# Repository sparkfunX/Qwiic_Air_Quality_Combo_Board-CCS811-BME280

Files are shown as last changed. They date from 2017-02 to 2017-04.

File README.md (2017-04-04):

Qwiic Air Quality Combo Board - CCS811 + BME280
========================================

Qwiic Air Quality Board

[*SPX-14241*](https://www.sparkfun.com/products/14241)

This combo board is the first of its kind to provide a variety of environmental data including barometric pressure, humidity, temperature, TVOCs, and CO2 levels, all over an easy to use I2C bus. The CCS811 is a very popular and very new TVOC and CO2 sensor. It has a feature that allows it to tune its internal algorithm and improve its readings if you provide the sensor with current humidity and temperature. Fortunately, the BME280 is an awesome sensor that outputs humidity, barometric pressure, and temperature. We decided to stick both on an easy to use board. We provide example code showing how to read humidity and pressure data from the BME280 and then transmit that data back to the CCS811 for improved TVOC and CO2 detection.

The [Qwiic system](http://www.sparkfun.com/qwiic) enables fast and solderless connection between popular platforms and various sensors and actuators. You can read more about the Qwiic system [here](http://www.sparkfun.com/qwiic). 

License Information
-------------------

This product is _**open source**_!

Please review the LICENSE.md file for license information.

If you have any questions or concerns on licensing, please contact techsupport@sparkfun.com.

Distributed as-is; no warranty is given.

- Your friends at SparkFun.

_<COLLABORATION CREDIT>_

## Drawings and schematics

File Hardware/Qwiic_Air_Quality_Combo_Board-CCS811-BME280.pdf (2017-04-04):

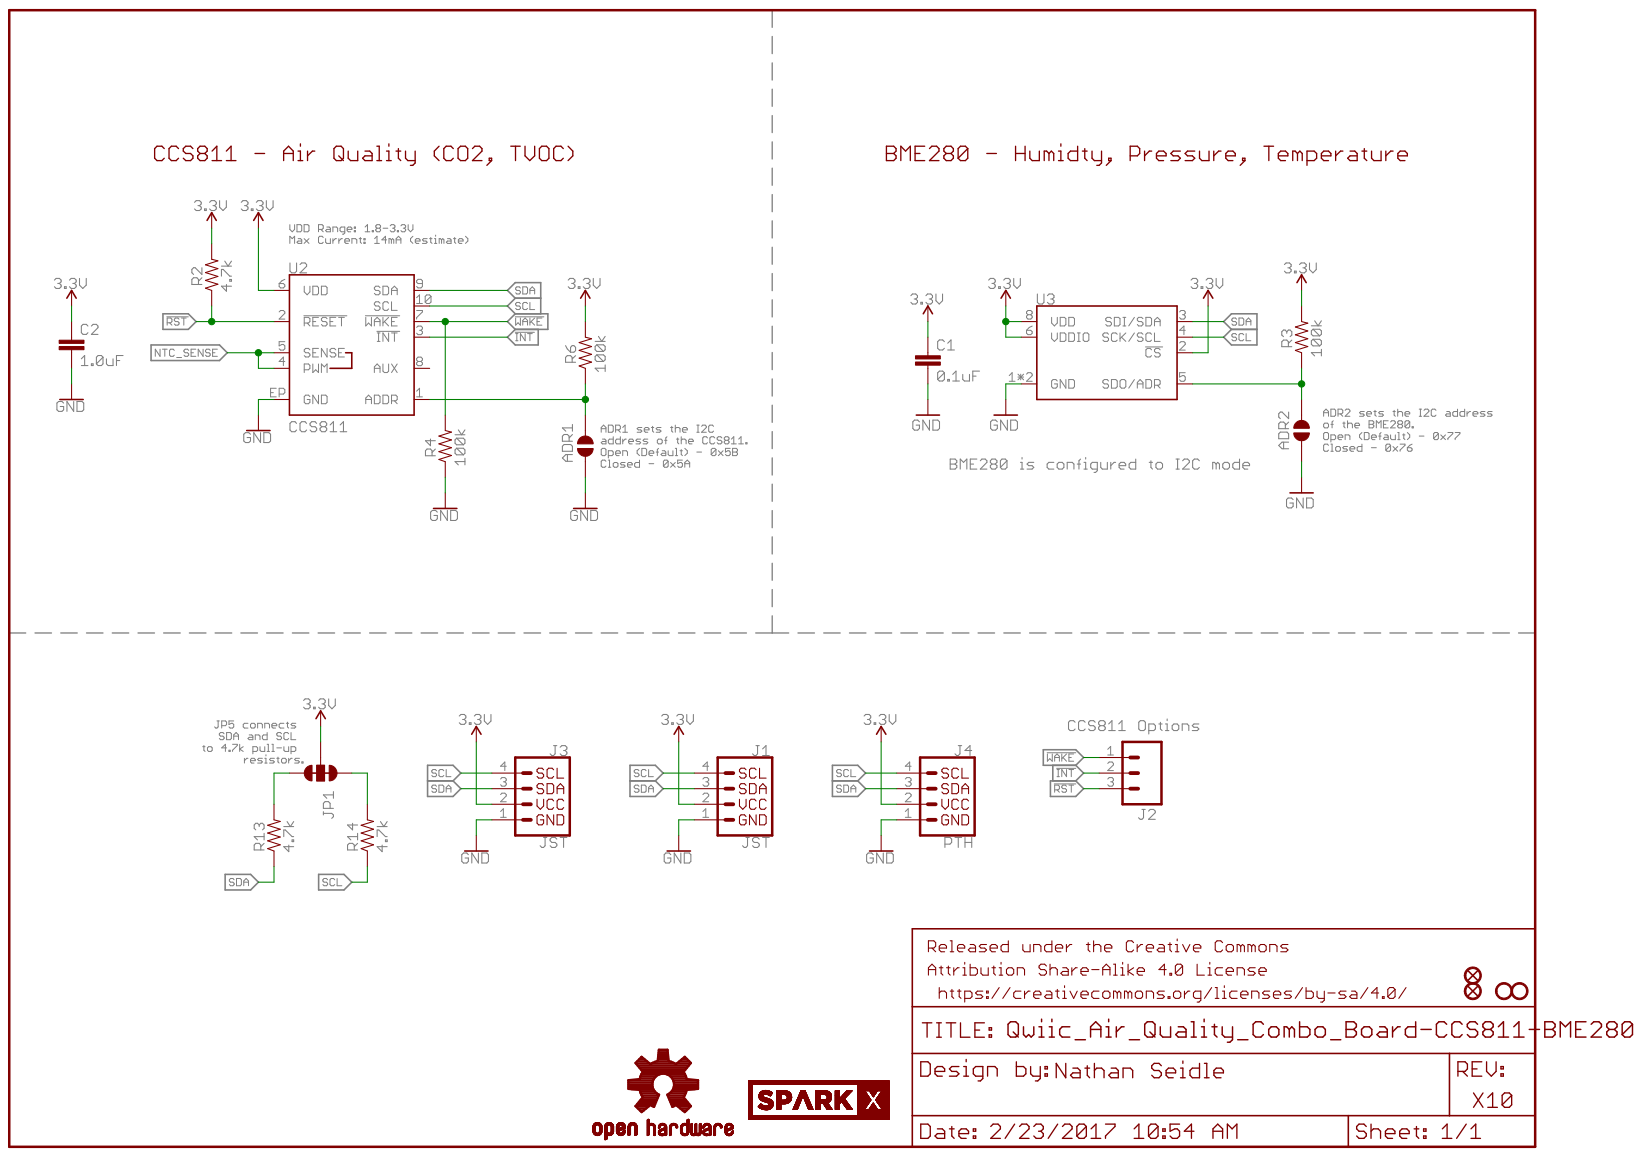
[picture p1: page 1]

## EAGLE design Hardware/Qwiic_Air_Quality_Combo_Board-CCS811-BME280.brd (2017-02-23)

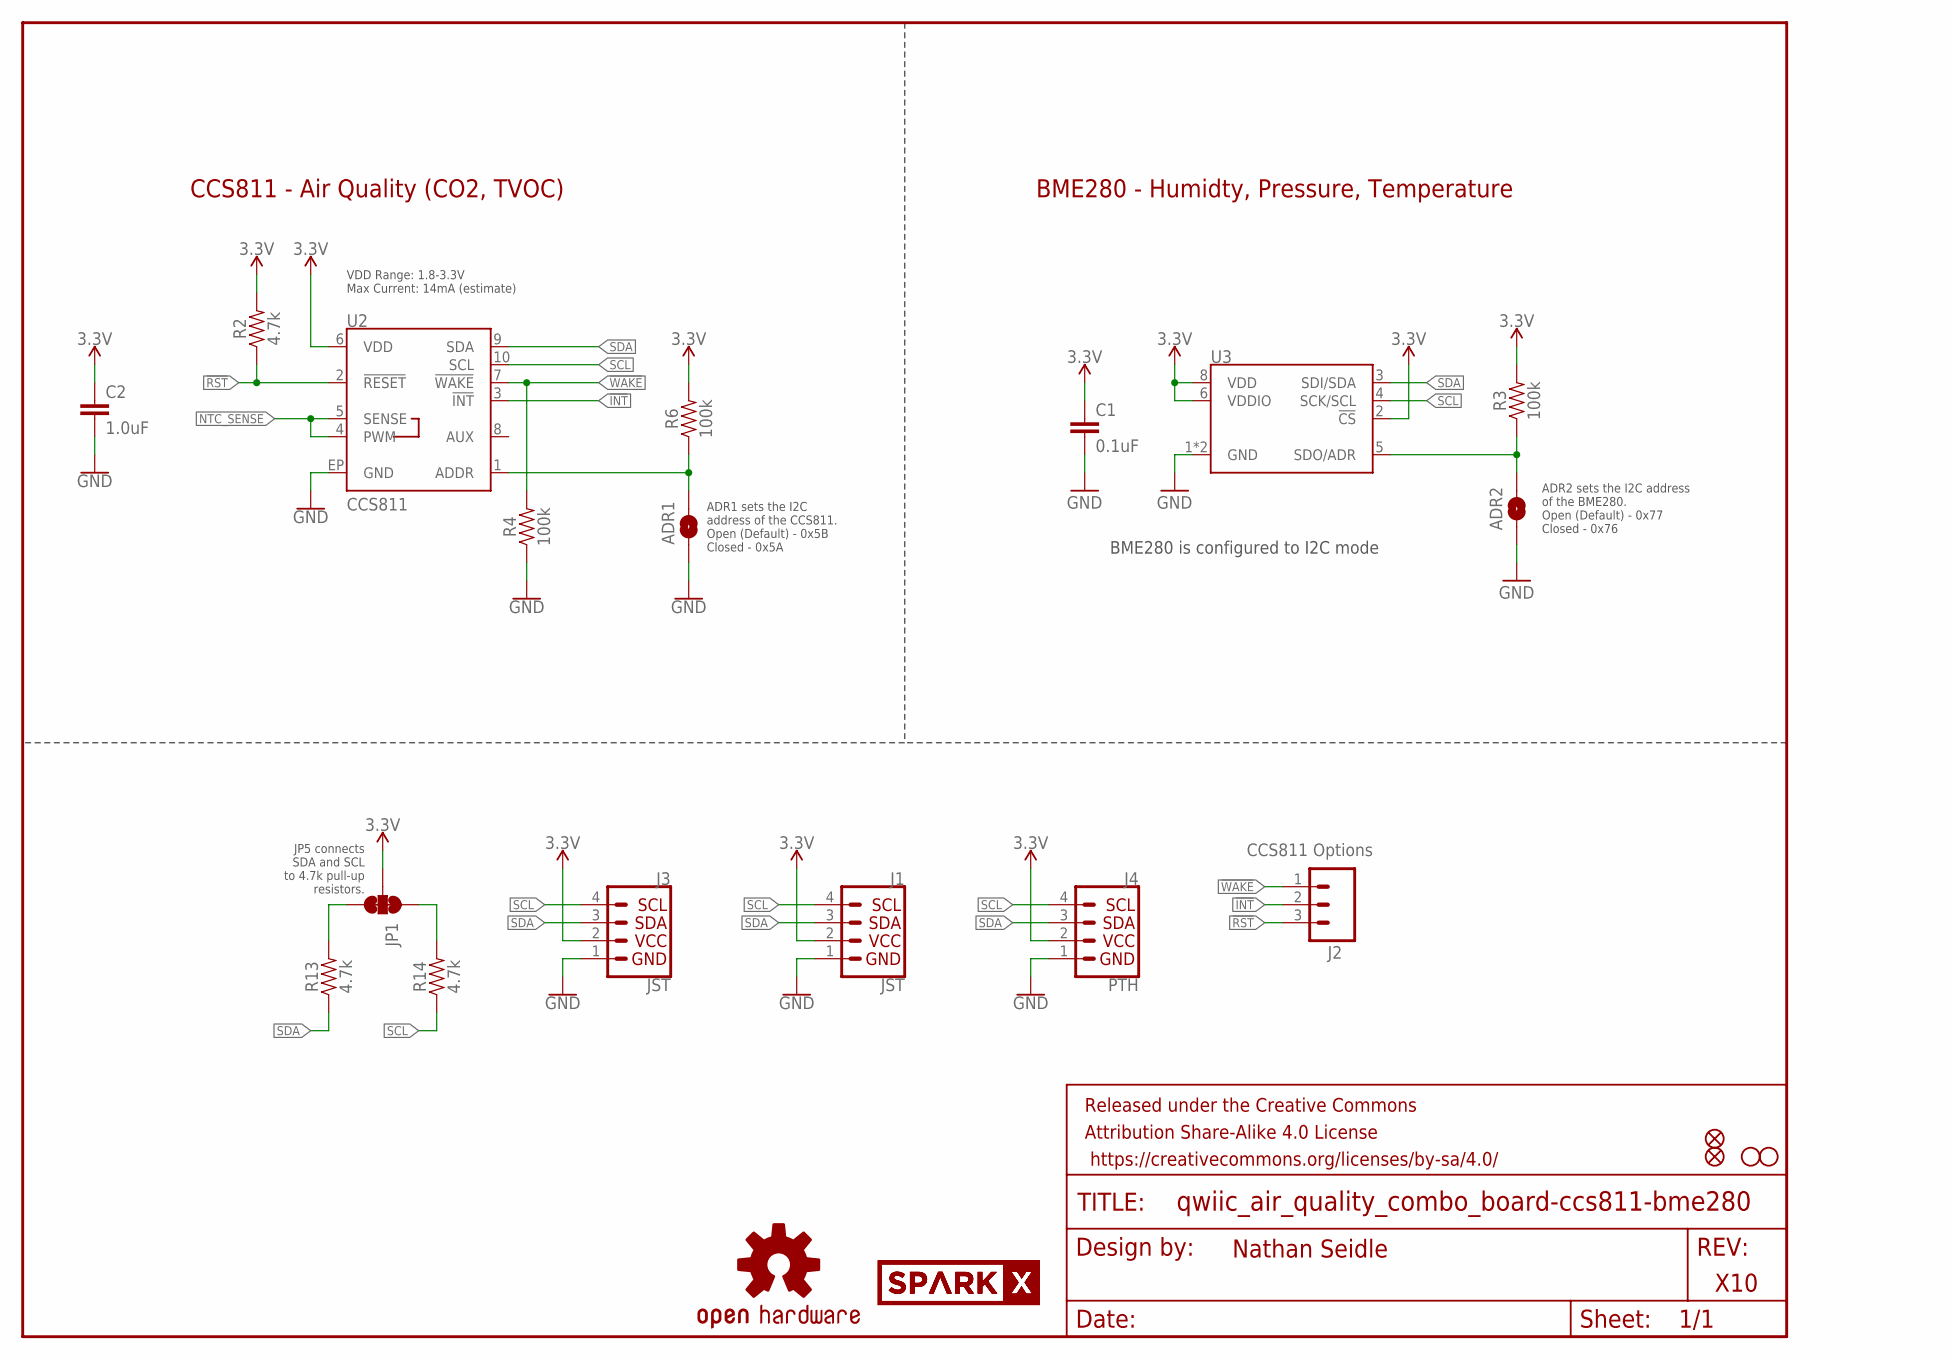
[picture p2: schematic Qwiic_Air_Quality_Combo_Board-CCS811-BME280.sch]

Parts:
ADR1, ADR2: JUMPER-SMT_2_NO_SILK; SMT-JUMPER_2_NO_SILK
C1: 0.1uF; 0603-CAP
C2: 1.0uF; 0603
FD1, FD2: FIDUCIAL1X2; FIDUCIAL-1X2
FRAME1: FRAME-LETTER; CREATIVE_COMMONS
H2, H4: STAND-OFF
J1, J3: JST; 1X04_1MM_RA
J2: CCS811 Options; 1X03_NO_SILK
J4: PTH; 1X04_NO_SILK
JP1: JUMPER-SMT_3_2-NC_TRACE_SILK; SMT-JUMPER_3_2-NC_TRACE_SILK
LOGO4: OSHW-LOGOS; OSHW-LOGO-S
R2, R13, R14: 4.7k; 0603
R3, R4, R6: 100k; 0603
U2: CCS811; LGA10
U3: BME280; BME280_LGA
U$1, U$2: SPARKX-LOGO4; SPARKX-MEDIUM

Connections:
3.3V: C1.1, C2.1, J1.2 (VCC), J3.2 (VCC), J4.2 (VCC), JP1.2, R2.2, R3.2, R6.2, U2.6 (VDD), U3.2 (!CS), U3.6 (VDDIO), U3.8 (VDD)
!INT: J2.2, U2.3 (!INT!)
!RST: J2.3, R2.1, U2.2 (!RESET!)
!WAKE: J2.1, R4.2, U2.7 (!WAKE!)
CCS811_ADDR: ADR1.2, R6.1, U2.1 (ADDR)
GND: ADR1.1, ADR2.1, C1.2, C2.2, J1.1 (GND), J3.1 (GND), J4.1 (GND), R4.1, U2.EP (GND), U3.1 (GND), U3.7 (GND)
unnamed: JP1.3, R13.2
unnamed: JP1.1, R14.2
NTC_SENSE: U2.4 (PWM), U2.5 (SENSE)
SCL: J1.4 (SCL), J3.4 (SCL), J4.4 (SCL), R14.1, U2.10 (SCL), U3.4 (SCK/SCL)
SDA: J1.3 (SDA), J3.3 (SDA), J4.3 (SDA), R13.1, U2.9 (SDA), U3.3 (SDI/SDA)
SDO/ADR: ADR2.2, R3.1, U3.5 (SDO/ADR)

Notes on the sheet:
VDD Range: 1.8-3.3V Max Current: 14mA (estimate)
CCS811 - Air Quality (CO2, TVOC)
ADR1 sets the I2C address of the CCS811. Open (Default) - 0x5B Closed - 0x5A
JP5 connects SDA and SCL to 4.7k pull-up resistors.
X10
Nathan Seidle
ADR2 sets the I2C address of the BME280. Open (Default) - 0x77 Closed - 0x76
BME280 is configured to I2C mode
BME280 - Humidty, Pressure, Temperature

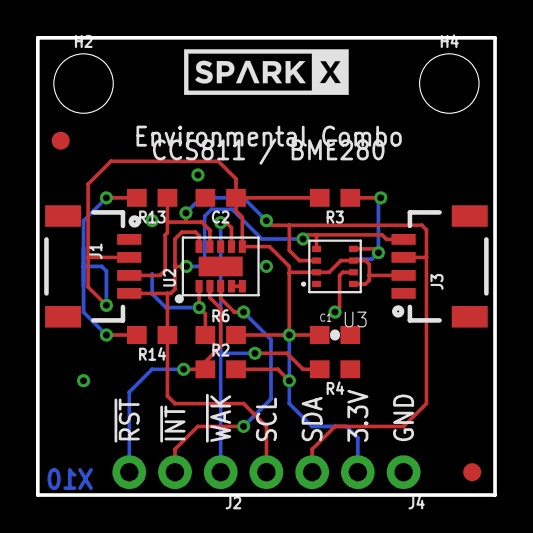
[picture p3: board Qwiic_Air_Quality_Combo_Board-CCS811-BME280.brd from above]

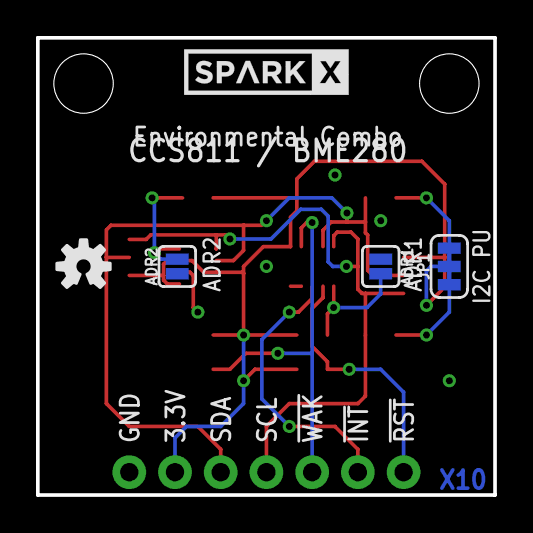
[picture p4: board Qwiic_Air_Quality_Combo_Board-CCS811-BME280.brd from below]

Board: 2 copper layers, 25.4 x 25.4 mm, 25 parts (5 on the bottom side), 12 nets.

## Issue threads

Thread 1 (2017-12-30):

problem working on esp8266

Giaitzoglou, 2017-12-30:
hi i succefully uploaded the example from your website withe combined readings but i always get an i2c error
.⸮EO⸮v`MM ⸮4C8I⸮⸮⸮H(⸮⸮⸮⸮BME280 data to CCS811 for compensation.
Problem with CCS811
I2C_ERRORProblem with BME280
can you please help me
thank in advance
chris giaitzoglou

Giaitzoglou, 2017-12-30:
i tried also the example with only the ccs811 but still having the same problem .it looks like that the i2c cant find it ?do i have to do anything to the board pullup or something i am using the qwiic to jumper cables on a breadboard with a wemos d1 mini
thanks

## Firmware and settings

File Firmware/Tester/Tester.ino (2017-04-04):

/*
  SparkFun combination CCS811 tVOC sensor combined with BME280 humidity, pressure, temp sensor
  By: Nathan Seidle
  SparkFun Electronics
  Date: April 3rd, 2017
  License: This code is public domain but you buy me a beer if you use this and we meet someday (Beerware license).

  This is a fast tester to verify both ICs are working.

  Hardware Connections:
  Attach a Qwiic Shield to your RedBoard, Photon, or ESP32.
  Plug the Qwiic Air Quality Combo board into one of the connectors
  Serial.print it out at 9600 baud to serial monitor.

*/

#include <Wire.h>
#include "SparkFunBME280.h" //Library for BME280 from library manager or https://github.com/sparkfun/SparkFun_BME280_Arduino_Library

BME280 pressureSensor;

#define CCS811_ADDR 0x5B //7-bit unshifted default I2C Address

//Register addresses
#define CSS811_STATUS 0x00
#define CSS811_MEAS_MODE 0x01
#define CSS811_ALG_RESULT_DATA 0x02
#define CSS811_RAW_DATA 0x03
#define CSS811_ENV_DATA 0x05
#define CSS811_NTC 0x06
#define CSS811_THRESHOLDS 0x10
#define CSS811_BASELINE 0x11
#define CSS811_HW_ID 0x20
#define CSS811_HW_VERSION 0x21
#define CSS811_FW_BOOT_VERSION 0x23
#define CSS811_FW_APP_VERSION 0x24
#define CSS811_ERROR_ID 0xE0
#define CSS811_APP_START 0xF4
#define CSS811_SW_RESET 0xFF

//These are the air quality values obtained from the sensor
unsigned int tVOC = 0;
unsigned int CO2 = 0;

void setup()
{
  Serial.begin(9600);
  Serial.println("CCS811+BME280 Read Example");

  Wire.begin();

  CO2 = 65535; //Set error condition
}

void loop()
{
  if (CO2 == 65535 || CO2 == 65534)
  {
    //No sensor detected, re-try setup
    if (configureCCS811() == false) //Turn on CCS811 sensor
      Serial.println("Problem with CCS811.");
    else
    {
      Serial.println("CCS811 GOOD");
      CO2 = 65534;
    }

    //Setup the BME280 for basic readings
    pressureSensor.settings.commInterface = I2C_MODE;
    pressureSensor.settings.I2CAddress = 0x77;
    pressureSensor.settings.runMode = 3; //  3, Normal mode
    pressureSensor.settings.tStandby = 0; //  0, 0.5ms
    pressureSensor.settings.filter = 0; //  0, filter off
    pressureSensor.settings.tempOverSample = 1;
    pressureSensor.settings.pressOverSample = 1;
    pressureSensor.settings.humidOverSample = 1;

    delay(10); //Give BME280 time to come on
    //Calling .begin() causes the settings to be loaded
    byte id = pressureSensor.begin(); //Returns ID of 0x60 if successful
    if (id != 0x60)
      Serial.println("Problem with BME280.");
    else
    {
      Serial.println("BME280 GOOD");
      if(CO2 == 65534) CO2 = 0; //All good! Clear error condition
    }

    delay(50);

  }
  else if (dataAvailable()) //Check to see if CCS811 has new data. It is the slowest sensor
  {
    readAlgorithmResults(); //Calling this function updates the global tVOC and CO2 variables

    float temperatureC = pressureSensor.readTempC();
    float pressure = pressureSensor.readFloatPressure();
    float humidity = pressureSensor.readFloatHumidity();

    Serial.print("CO2[");
    Serial.print(CO2);
    Serial.print("] tVOC[");
    Serial.print(tVOC);
    Serial.print("] humidity[");
    Serial.print(humidity, 0);
    Serial.print("] pressure[");
    Serial.print(pressure, 0);
    Serial.print("] temperatureC[");
    Serial.print(temperatureC, 1);
    Serial.print("] millis[");
    Serial.print(millis());
    Serial.print("]");
    Serial.println();
  }
  else if (checkForError())
  {
    printError();
  }

  delay(100); //Wait for next reading
}

//Updates the total voltatile organic compounds (TVOC) in parts per billion (PPB)
//and the CO2 value
//Returns nothing
void readAlgorithmResults()
{
  Wire.beginTransmission(CCS811_ADDR);
  Wire.write(CSS811_ALG_RESULT_DATA);
  Wire.endTransmission();

  Wire.requestFrom(CCS811_ADDR, 4); //Get four bytes

  byte co2MSB = Wire.read();
  byte co2LSB = Wire.read();
  byte tvocMSB = Wire.read();
  byte tvocLSB = Wire.read();

  CO2 = ((unsigned int)co2MSB << 8) | co2LSB;
  tVOC = ((unsigned int)tvocMSB << 8) | tvocLSB;
}

//Turns on the sensor and configures it with default settings
boolean configureCCS811()
{
  //Verify the hardware ID is what we expect
  byte hwID = readRegister(0x20); //Hardware ID should be 0x81
  if (hwID != 0x81)
  {
    Serial.print("Hardware ID wrong: 0x");
    Serial.println(hwID, HEX);
    return (false);
  }

  //Check for errors
  if (checkForError() == true)
  {
    Serial.println("Error at Startup");
    printError();
    return (false);
  }

  //Tell App to Start
  if (appValid() == false)
  {
    Serial.println("Error: App not valid.");
    return (false);
  }

  //Write to this register to start app
  Wire.beginTransmission(CCS811_ADDR);
  Wire.write(CSS811_APP_START);
  Wire.endTransmission();

  //Check for errors
  if (checkForError() == true)
  {
    Serial.println("Error at AppStart");
    printError();
    return (false);
  }

  //Set Drive Mode
  setDriveMode(1); //Read every second

  //Check for errors
  if (checkForError() == true)
  {
    Serial.println("Error at setDriveMode");
    printError();
    return (false);
  }

  return (true); //All set!
}

//Checks to see if error bit is set
boolean checkForError()
{
  byte value = readRegister(CSS811_STATUS);
  return (value & 1 << 0);
}

//Displays the type of error
//Calling this causes reading the contents of the ERROR register
//This should clear the ERROR_ID register
void printError()
{
  byte error = readRegister(CSS811_ERROR_ID);

  Serial.print("Error: ");
  if (error & 1 << 5) Serial.print("HeaterSupply ");
  if (error & 1 << 4) Serial.print("HeaterFault ");
  if (error & 1 << 3) Serial.print("MaxResistance ");
  if (error & 1 << 2) Serial.print("MeasModeInvalid ");
  if (error & 1 << 1) Serial.print("ReadRegInvalid ");
  if (error & 1 << 0) Serial.print("MsgInvalid ");

  Serial.println();
}

//Returns the baseline value
//Used for telling sensor what 'clean' air is
//You must put the sensor in clean air and record this value
unsigned int getBaseline()
{
  Wire.beginTransmission(CCS811_ADDR);
  Wire.write(CSS811_BASELINE);
  Wire.endTransmission();

  Wire.requestFrom(CCS811_ADDR, 2); //Get two bytes

  byte baselineMSB = Wire.read();
  byte baselineLSB = Wire.read();

  unsigned int baseline = ((unsigned int)baselineMSB << 8) | baselineLSB;

  return (baseline);
}

//Checks to see if DATA_READ flag is set in the status register
boolean dataAvailable()
{
  byte value = readRegister(CSS811_STATUS);
  return (value & 1 << 3);
}

//Checks to see if APP_VALID flag is set in the status register
boolean appValid()
{
  byte value = readRegister(CSS811_STATUS);
  return (value & 1 << 4);
}

//Enable the nINT signal
void enableInterrupts(void)
{
  byte setting = readRegister(CSS811_MEAS_MODE); //Read what's currently there
  setting |= (1 << 3); //Set INTERRUPT bit
  writeRegister(CSS811_MEAS_MODE, setting);
}

//Disable the nINT signal
void disableInterrupts(void)
{
  byte setting = readRegister(CSS811_MEAS_MODE); //Read what's currently there
  setting &= ~(1 << 3); //Clear INTERRUPT bit
  writeRegister(CSS811_MEAS_MODE, setting);
}

//Mode 0 = Idle
//Mode 1 = read every 1s
//Mode 2 = every 10s
//Mode 3 = every 60s
//Mode 4 = RAW mode
void setDriveMode(byte mode)
{
  if (mode > 4) mode = 4; //Error correction

  byte setting = readRegister(CSS811_MEAS_MODE); //Read what's currently there

  setting &= ~(0b00000111 << 4); //Clear DRIVE_MODE bits
  setting |= (mode << 4); //Mask in mode
  writeRegister(CSS811_MEAS_MODE, setting);
}

//Given a temp and humidity, write this data to the CSS811 for better compensation
//This function expects the humidity and temp to come in as floats
void setEnvironmentalData(float relativeHumidity, float temperature)
{
  int rH = relativeHumidity * 1000; //42.348 becomes 42348
  int temp = temperature * 1000; //23.2 becomes 23200

  byte envData[4];

  //Split value into 7-bit integer and 9-bit fractional
  envData[0] = ((rH % 1000) / 100) > 7 ? (rH / 1000 + 1) << 1 : (rH / 1000) << 1;
  envData[1] = 0; //CCS811 only supports increments of 0.5 so bits 7-0 will always be zero
  if (((rH % 1000) / 100) > 2 && (((rH % 1000) / 100) < 8))
  {
    envData[0] |= 1; //Set 9th bit of fractional to indicate 0.5%
  }

  temp += 25000; //Add the 25C offset
  //Split value into 7-bit integer and 9-bit fractional
  envData[2] = ((temp % 1000) / 100) > 7 ? (temp / 1000 + 1) << 1 : (temp / 1000) << 1;
  envData[3] = 0;
  if (((temp % 1000) / 100) > 2 && (((temp % 1000) / 100) < 8))
  {
    envData[2] |= 1;  //Set 9th bit of fractional to indicate 0.5C
  }

  Wire.beginTransmission(CCS811_ADDR);
  Wire.write(CSS811_ENV_DATA); //We want to write our RH and temp data to the ENV register
  Wire.write(envData[0]);
  Wire.write(envData[1]);
  Wire.write(envData[2]);
  Wire.write(envData[3]);
}

//Reads from a give location from the CSS811
byte readRegister(byte addr)
{
  Wire.beginTransmission(CCS811_ADDR);
  Wire.write(addr);
  Wire.endTransmission();

  Wire.requestFrom(CCS811_ADDR, 1);

  return (Wire.read());
}

//Write a value to a spot in the CCS811
void writeRegister(byte addr, byte val)
{
  Wire.beginTransmission(CCS811_ADDR);
  Wire.write(addr);
  Wire.write(val);
  Wire.endTransmission();
}

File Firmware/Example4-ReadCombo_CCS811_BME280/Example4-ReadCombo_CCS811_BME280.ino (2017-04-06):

/*
  Read both CCS811 and BME280 sensors at same time
  By: Nathan Seidle
  SparkFun Electronics
  Date: April 6th, 2017
  License: This code is public domain but you buy me a beer if you use this and we meet someday (Beerware license).

  Works with SparkFun combo board https://www.sparkfun.com/products/14241
  Enjoy this code? Buy a board and help support SparkFun! 
  
  Let's read both sensors at the same time!
  Outputs CO2, TVOC, temperature, humidty, and pressure.
  
  Hardware Connections (Breakoutboard to Arduino):
  Attach a Qwiic Shield to your RedBoard, Photon, or ESP32.
  Plug the Qwiic Air Quality Combo board into one of the connectors
  Serial.print it out at 9600 baud to serial monitor.

*/

#include <Wire.h>
#include "SparkFunBME280.h" //Library for BME280 from library manager or https://github.com/sparkfun/SparkFun_BME280_Arduino_Library

BME280 myBME280; //Global sensor object for BME280

//Global variables obtained from the two sensors
unsigned int tVOC = 0;
unsigned int CO2 = 0;
float tempf = 0;
float humidity = 0;
float pressureInHg = 0;

void setup()
{
  Serial.begin(9600);
  Serial.println("CCS811+BME280 Read Example");

  Wire.begin();

  if (configureCCS811() == false)
  {
    Serial.println("Problem with CCS811");
  }
  else
  {
    Serial.println("CCS811 online");
  }

  //Setup the BME280 for basic readings
  myBME280.settings.commInterface = I2C_MODE;
  myBME280.settings.I2CAddress = 0x77;
  myBME280.settings.runMode = 3; //  3, Normal mode
  myBME280.settings.tStandby = 0; //  0, 0.5ms
  myBME280.settings.filter = 0; //  0, filter off
  myBME280.settings.tempOverSample = 1;
  myBME280.settings.pressOverSample = 1;
  myBME280.settings.humidOverSample = 1;

  delay(10); //Give BME280 time to come on
  //Calling .begin() causes the settings to be loaded
  byte id = myBME280.begin(); //Returns ID of 0x60 if successful
  if (id != 0x60)
  {
    Serial.println("Problem with BME280");
  }
  else
  {
    Serial.println("BME280 online");
  }
}

void loop()
{
  if (dataAvailable()) //Check to see if CCS811 has new data (it's the slowest sensor)
  {
    readAlgorithmResults(); //Read latest from CCS811 and update tVOC and CO2 variables
    getWeather(); //Get latest humidity/pressure/temp data from BME280
    printData(); //Pretty print all the data
  }
  else if (checkForError()) //Check to see if CCS811 has thrown an error
  {
    printError(); //Prints whatever CSS811 error flags are detected
  }

  delay(2000); //Wait for next reading
}

//Gets the latest temperature, pressure and humidity from BME280
void getWeather()
{
  //Measure the Barometer temperature in F from the BME280
  tempf = myBME280.readTempF();

  //Measure Pressure from the BME280
  float pascals = myBME280.readFloatPressure();
  pressureInHg = pascals * 0.0002953; // Calc for converting Pa to inHg

  // Measure Relative Humidity from the BME280
  humidity = myBME280.readFloatHumidity();
}

//Print CO2, TVOC, Humidity, Pressure and Temp
void printData()
{
  Serial.print(" CO2[");
  Serial.print(CO2);
  Serial.print("]ppm");

  Serial.print(" TVOC[");
  Serial.print(tVOC);
  Serial.print("]ppb");

  Serial.print(" temp[");
  Serial.print(myBME280.readTempC(), 1);
  Serial.print("]C");

  //Serial.print(" temp[");
  //Serial.print(myBME280.readTempF(), 1);
  //Serial.print("]F");

  Serial.print(" pressure[");
  Serial.print(myBME280.readFloatPressure(), 2);
  Serial.print("]Pa");

  //Serial.print(" pressure[");
  //Serial.print((myBME280.readFloatPressure() * 0.0002953), 2);
  //Serial.print("]InHg");

  //Serial.print("altitude[");
  //Serial.print(myBME280.readFloatAltitudeMeters(), 2);
  //Serial.print("]m");

  //Serial.print("altitude[");
  //Serial.print(myBME280.readFloatAltitudeFeet(), 2);
  //Serial.print("]ft");

  Serial.print(" humidty[");
  Serial.print(myBME280.readFloatHumidity(), 0);
  Serial.print("]%");

  Serial.println();
}

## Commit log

2017-02-21 Initial combination schematic and layout
    [CSS811_BME280_Breakout.brd, CSS811_BME280_Breakout.sch]
2017-02-22 Initial Layout Finished - Ready for Review
    [CSS811_BME280_Breakout.brd, CSS811_BME280_Breakout.sch]
2017-02-23 Adjusted component to avoid silk.
    [CSS811_BME280_Breakout.brd]
2017-02-23 Panel of X10 with vscore and frame indicators
    [CCS811 BME280 Panel.brd]
2017-02-23 Adding gerbers of panel
    [CCS811 BME280 Panel.GBL, CCS811 BME280 Panel.GBO, CCS811 BME280 Panel.GBS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]
2017-02-23 Panel that is now 3x4pcs
    [CCS811 BME280 Panel.GBL, CCS811 BME280 Panel.GBO, CCS811 BME280 Panel.GBS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]
2017-02-28 Working on temp&humidity compensation more
    Working on temp&humidity compensation more. Can see bytes being sent,
    but can’t seem to read the register to see if they are in fact being
    compensated for.
2017-04-04 Fixing file names
    [CCS811 BME280 Panel.GBL, CCS811 BME280 Panel.GBO, CCS811 BME280 Panel.GBS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]

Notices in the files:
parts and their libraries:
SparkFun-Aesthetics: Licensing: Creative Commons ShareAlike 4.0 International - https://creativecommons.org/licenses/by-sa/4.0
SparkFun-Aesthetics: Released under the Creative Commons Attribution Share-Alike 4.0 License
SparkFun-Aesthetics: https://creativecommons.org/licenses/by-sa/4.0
